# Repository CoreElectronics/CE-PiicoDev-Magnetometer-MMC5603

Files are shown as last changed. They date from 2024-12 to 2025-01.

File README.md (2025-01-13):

# PiicoDev® Magnetometer MMC5603



This is the repo for the Core Electronics [PiicoDev Magnetometer MMC5603](https://core-electronics.com.au/catalog/product/view/sku/CE10107).

The PiicoDev® Magnetometer measures invisible magnetic fields. It's sensitive enough to use as a compass and wide-range enough for detecting magnets - which have a much stronger field. The on-board MMC5603 can measure up to 20-bits up to 3000μT in all 3 axes. By using PiicoDev adapters and cables, you can connect to this sensor without soldering - or use the standard breakout header if you prefer breadboard prototyping. Whichever you prefer, the PiicoDev guides will guide you through exciting experiments like measuring the Earth's magnetic field to find a heading and detecting if a magnet is nearby.

**Features**

- Small size, high accuracy
- Measures magnetic fields in 3-axes
- Sensitive enough to use like a compass, 
- A broad enough range to work with nearby magnets
- Great guides to get you started
- PiicoDev connector, compatible with Qwiic and STEMMA QT (3.3V only)
- 2.54mm breakout for breadboarding/prototyping
- Manufactured and supported in Australia by Core Electronics

## License
This project is open source - please review the LICENSE.md file for further licensing information.

If you have any technical questions, or concerns about licensing, please contact technical support on the [Core Electronics forums](https://forum.core-electronics.com.au/).

*\"PiicoDev\" and the PiicoDev logo are trademarks of Core Electronics Pty Ltd.*

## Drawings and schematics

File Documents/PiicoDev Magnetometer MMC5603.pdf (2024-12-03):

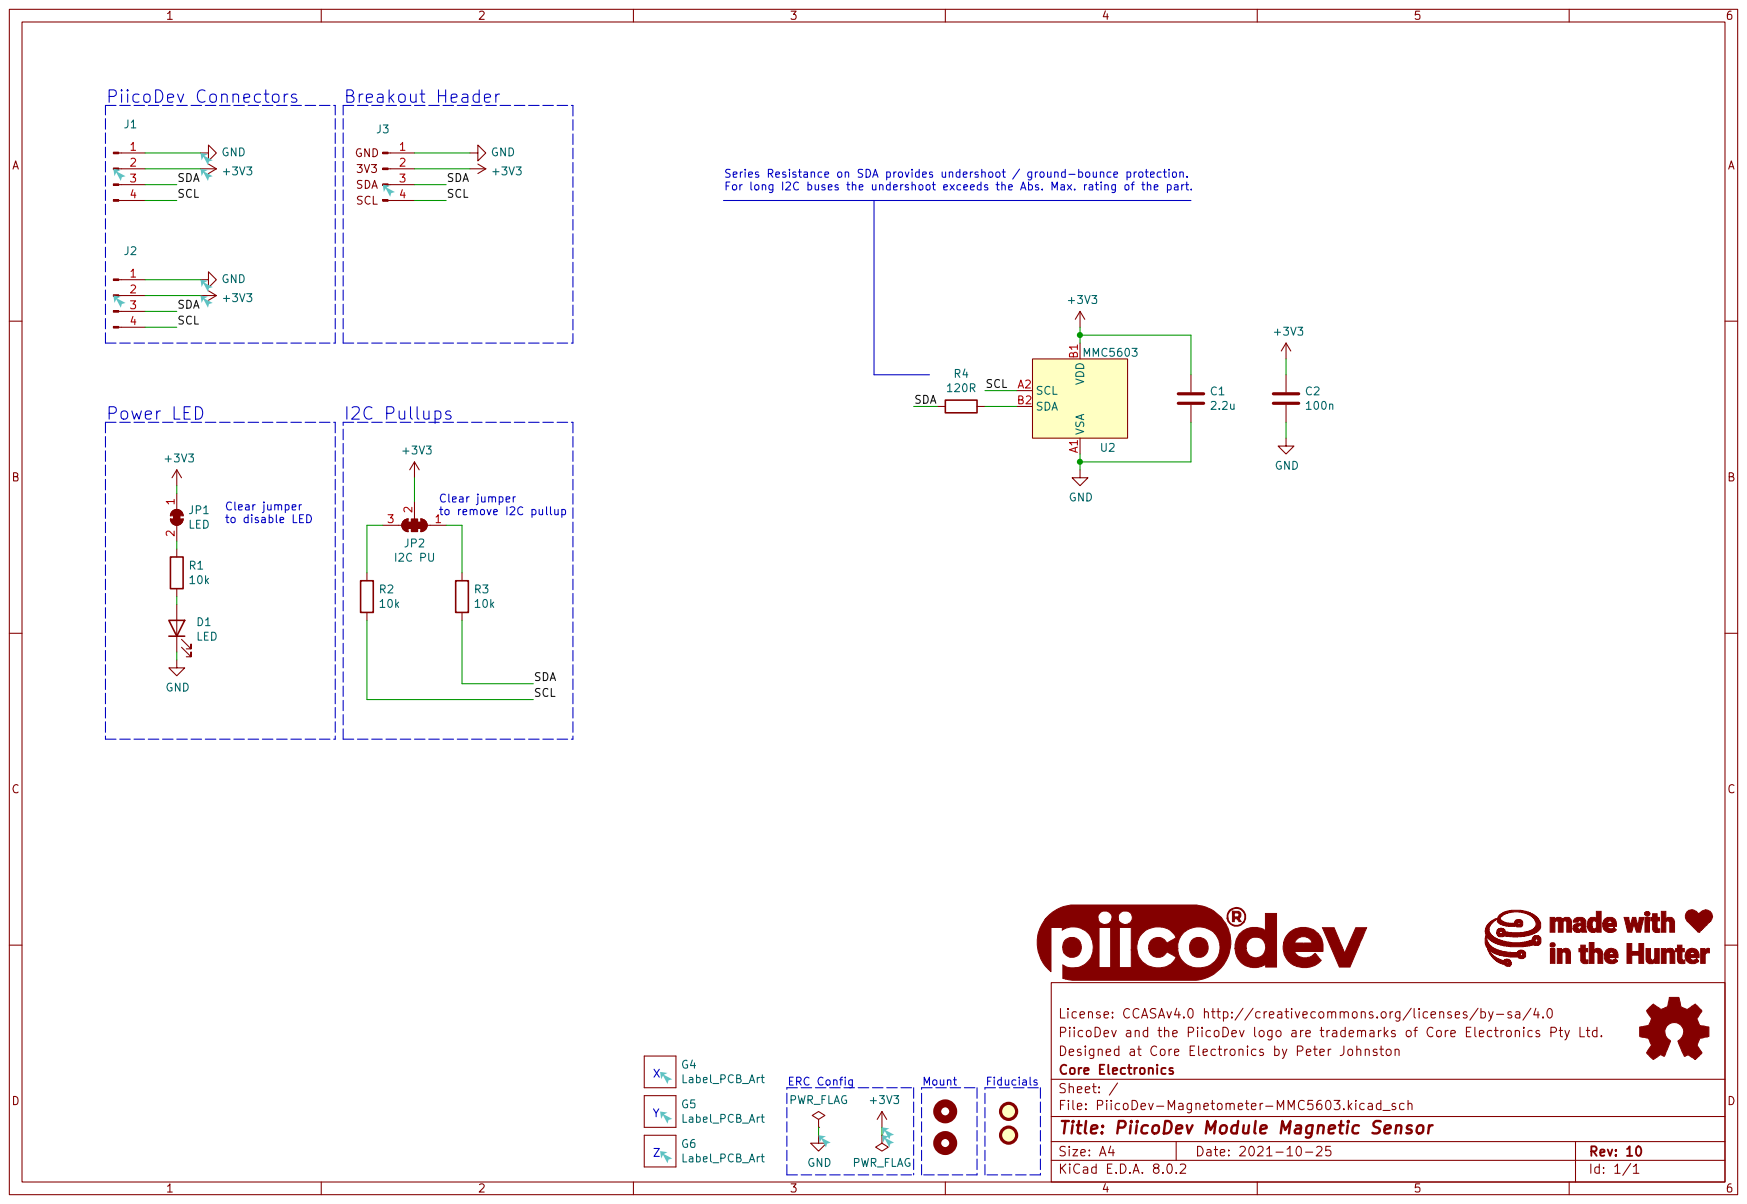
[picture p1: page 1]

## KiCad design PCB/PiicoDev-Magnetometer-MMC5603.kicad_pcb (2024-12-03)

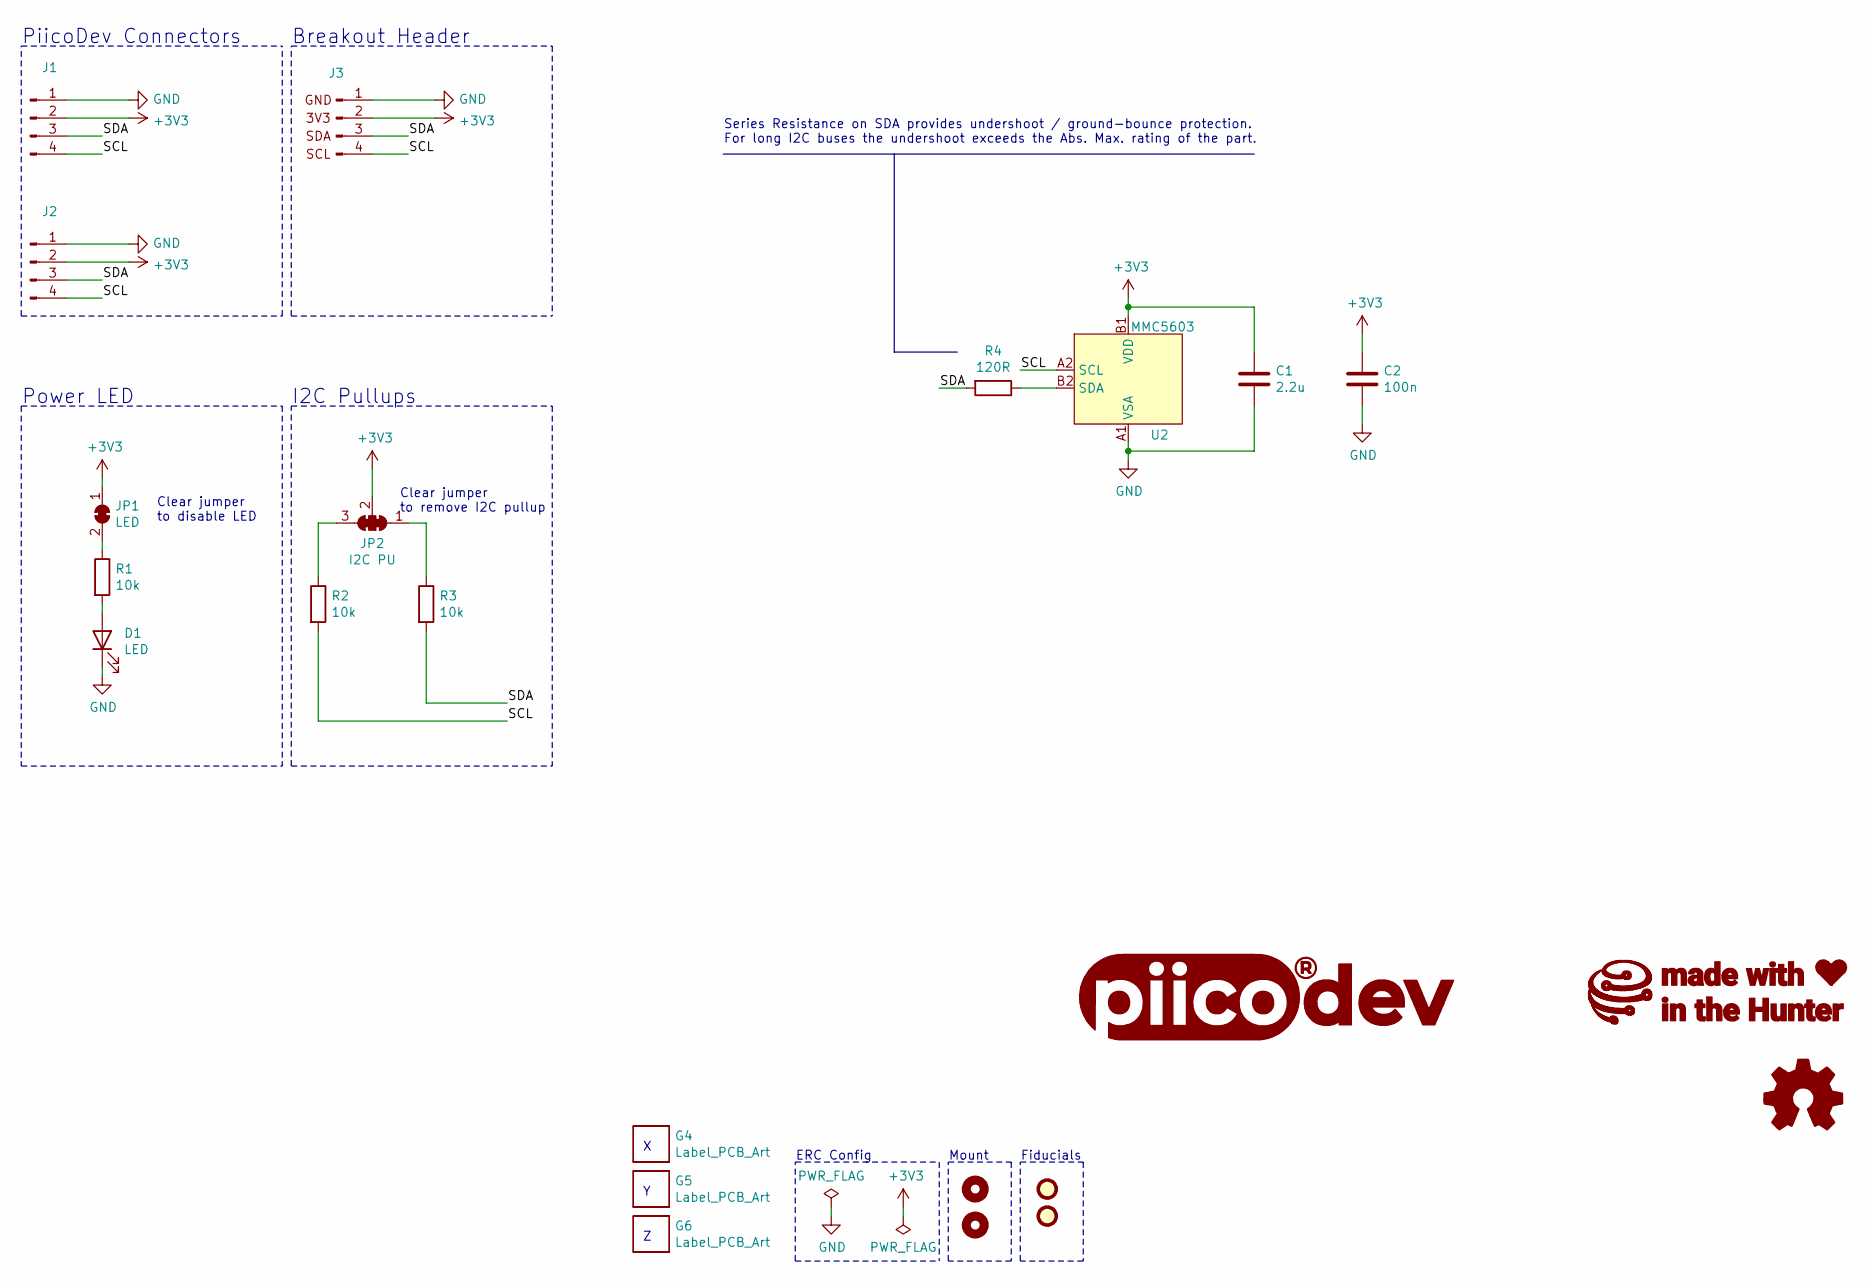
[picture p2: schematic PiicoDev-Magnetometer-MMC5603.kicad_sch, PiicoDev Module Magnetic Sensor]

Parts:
C1: 2.2u; C_0402_1005Metric
C2: 100n; C_0402_1005Metric
D1: LED; LED_0603_1608Metric
FID1, FID2: Fiducial; Fiducial_1mm_Mask2mm
G1: LOGO_PiicoDev; piicodev_logo_14.2x3.4mm
G2: LOGO_CoreElectronics_no-text; CoreElectronics_logo_5mm
G3: LOGO_made-with-love; piicodev_logo_14.2x3.4mm
G4: Label_PCB_Art; Axes_and_polarity_X
G5: Label_PCB_Art; Axes_and_polarity_Y
G6: Label_PCB_Art; Axes_and_polarity_Z
H1, H2: MountingHole; MountingHole_2.7mm_M2.5_PadClearance_1.2
J1, J2: JST_SH_SM04B-SRSS-TB_1x04-1MP_P1.00mm_Horizontal
J3: Conn_PiicoDev_header_01x04_Male; PiicoDev_header_4pin
JP1: LED; SolderJumper-2_P1.3mm_Bridged_RoundedPad1.0x1.5mm
JP2: I2C PU; SolderJumper-3_P1.3mm_Closed_RoundedPad1.0x1.5mm_NumberLabe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
LOGO1: Logo_Open_Hardware_Small; oshw
R1, R2, R3: 10k; R_0402_1005Metric
R4: 120R; R_0402_1005Metric
U2: MMC5603

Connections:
+3V3: C1.1, C2.1, J1.2, J2.2, J3.2, JP1.1 (A), JP2.2 (C), U2.B1 (VDD)
/SCL: J1.4, J2.4, J3.4, R2.2, U2.A2 (SCL)
/SDA: J1.3, J2.3, J3.3, R3.2, R4.2
GND: C1.2, C2.2, D1.1 (K), J1.1, J2.1, J3.1, U2.A1 (VSA)
unnamed: D1.2 (A), R1.2
unnamed: JP1.2 (B), R1.1
unnamed: JP2.1 (A), R3.1
unnamed: JP2.3 (B), R2.1
unnamed: R4.1, U2.B2 (SDA)

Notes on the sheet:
ERC Config
PiicoDev Connectors
Breakout Header
Mount
Fiducials
Series Resistance on SDA provides undershoot / ground-bounce protection. For long I2C buses the undershoot exceeds the Abs. Max. rating of the part.
Clear jumper to disable LED
Power LED
Clear jumper to remove I2C pullup
I2C Pullups

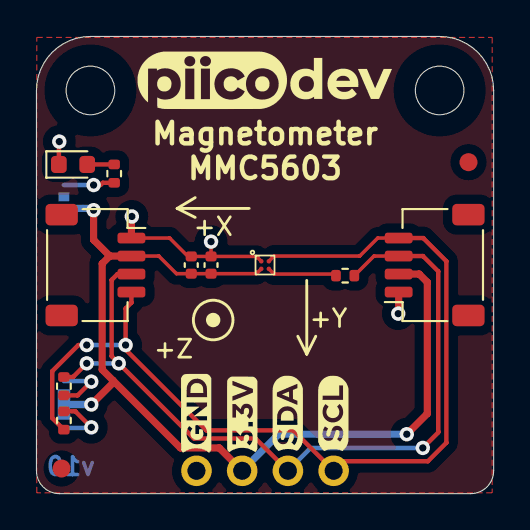
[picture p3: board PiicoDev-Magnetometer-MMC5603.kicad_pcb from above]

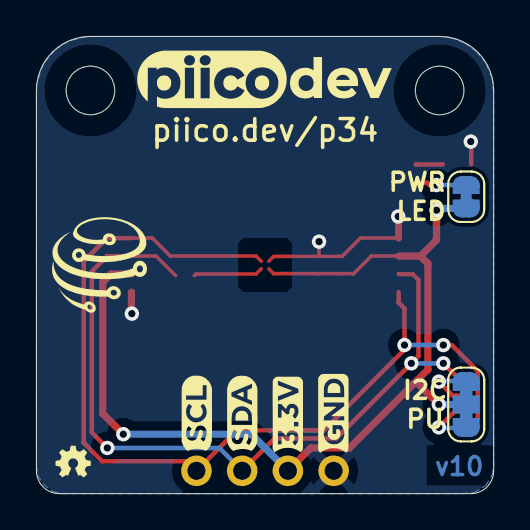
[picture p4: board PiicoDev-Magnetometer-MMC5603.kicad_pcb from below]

Board: 2 copper layers, 25.4 x 25.4 mm, 24 parts (6 on the bottom side), 9 nets.

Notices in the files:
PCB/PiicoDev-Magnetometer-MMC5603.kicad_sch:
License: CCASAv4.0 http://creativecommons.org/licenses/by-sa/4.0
